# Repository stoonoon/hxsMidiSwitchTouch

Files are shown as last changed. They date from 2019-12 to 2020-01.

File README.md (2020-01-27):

# hxsMidiSwitchTouch
v2 of hxsMidiSwitcher - This time with touchscreen and expression pedal input

Still in the very early stages of how to go about this, so doubtless lots will change. That said, it's complete enough that my prototype unit is functional enough for me to use. Now I know I can make it work, I need to go back over it all and restructure the code so that it's less of a shambles.

At the moment the touchscreen is primarily to cycle between preset pages, but you can also tap the button labels to trigger a single press action.

The physical footswitches are working and sending midi messages over to the stomp. 
Expression pedal and toeswitch is working fairly well... I'm currently using a slightly modified crybaby wah with the circuit board removed, and a TRS jack connected to the potentiometer/toeswitch harness... Not ideal as it's a log pot rather than a linear one but with some software compensation it seems good enough for now.

# Combo press / long press actions
 - Switch layout:
[0 1 2 3]
[4 5 6 7]
- Combo press (all pages)
-- 0+4 - Preset Down
-- 3+7 - Preset Up
-- 6+7 - Tuner
-- 0+1 - switcher Page Down
-- 2+3 - switcher Page Up
- Long Press (all pages)
-- 3 - Tuner

## Working so far
- Touchscreen
-- << and >> buttons cycle between preset pages
-- Footswitch labels update as preset page changes
-- Touching the footswitch label triggers a FS short click action for that switch
- Midi
-- PC / CC messages
-- macro of several messages sent in a chain (needed for preset up/down functionality without relying on FS4/FS5 being dedicated to it in the Stomp global settings)
- Expression pedal
-- Converts resistance from 100kOhm log pot to MIDI byte
-- Sends to Stomp as either EXP1, EXP2 or both
-- Checks for changes in latching toeswitch & sends FS5 to Stomp
- switch preset page from footswitches
- toggle mode (FS function & label changes to next in list after press) - see looper Fwd/Rev and Full/Half speed for an example

## Still to do:
- Refactor the code so it plays nicely in VSCode - it doesn't seem to like multiple .ino files
- Move current_millis declaration from global to local in whichever functions need it. (exp_pedal.ino)
- Move other exp pedal variables to static within functions where possible
- Rename MidiMessage/MidiMessageToggler/MidiNullMessage to FootswitchAction*
- 
- Programming screen on nextion & associated code on arduino
- Ability to save/load custom programs to/from eeprom
- Document the calculations for the expression pedal log pot compensation
- Document the wiring adapter for the wah pedal to expression pedal conversion.
- configurable for log/lin EXP pedal pots
- configurable for TRS pedal pot type input or TS + voltage divider style
- configurable for latching/momentary toeswitch
- configurable for +5v toeswitch with external pulldown, or GND toeswitch with internal pullup
- All the other stuff I can't remember at the moment or haven't thought of yet

## Maybe considering, but probably not until v3
- power capacitor needed for nextion screen? seems OK without.. will see if it holds up
- activate long press/double FS actions from touchscreen 
- USB host midi capability - to be able to control Zoom B3/G3n/MS60B type pedals etc
- extra MIDI in/out ports
- bluetooth
- self-hovering

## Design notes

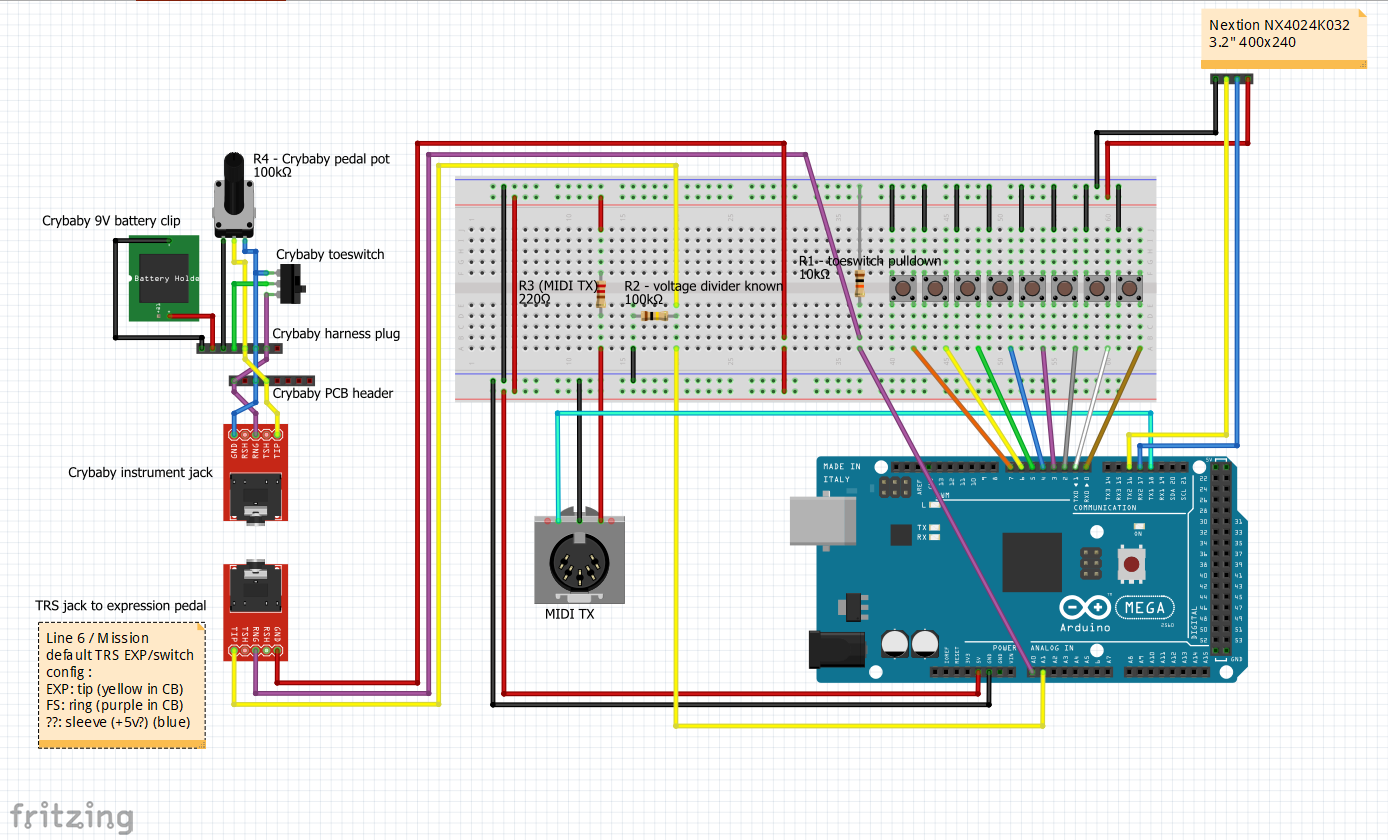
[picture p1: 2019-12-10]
hxsMidiSwitchTouch-breadboard.png

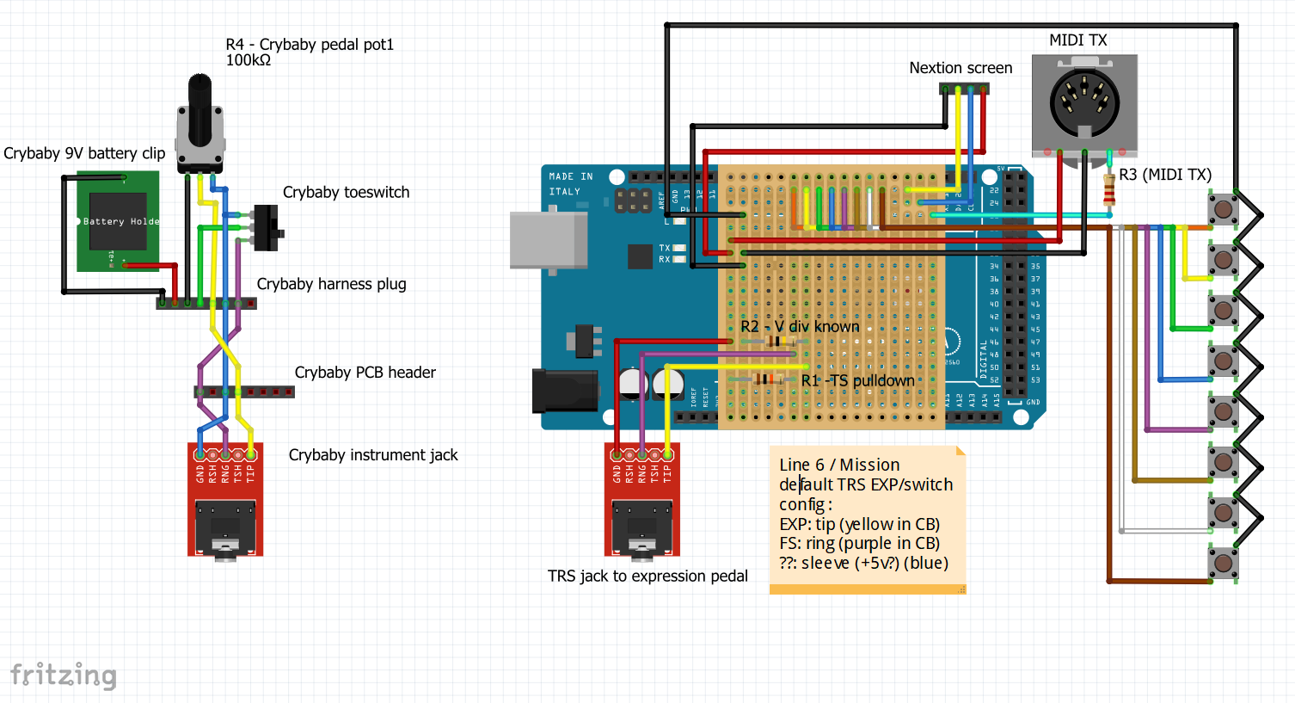
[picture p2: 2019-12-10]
hxsMidiSwitchTouch-shield.png

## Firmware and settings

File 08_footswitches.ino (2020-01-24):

//default config for footswitch single tap actions
MidiMessage *page0SingleActions[] = {&hxsSnap1, &hxsSnap2, &hxsSnap3, &hxsTuner, 
                            &hxsFS1, &hxsFS2, &hxsFS3, &hxsTapTempo};
MidiMessage *page1SingleActions[] = {&hxsSnap1, &hxsSnap2, &hxsSnap3, &hxsFS5, 
                        &hxsFS1, &hxsFS2, &hxsFS3, &hxsFS4};
MidiMessage *page2SingleActions[] = {&hxsSnap1, &hxsSnap2, &hxsSnap3, &hxsPresetUpMacro, 
                        &hxsFS1, &hxsFS2, &hxsFS3, &hxsPresetDownMacro};
MidiMessage *page3SingleActions[] = {&hxsFS4, &hxsFS5, &hxsPresetDownMacro, &hxsPresetUpMacro, 
                        &hxsFS1, &hxsFS2, &hxsFS3, &hxsTapTempo};
MidiMessage *page4SingleActions[] = {&hxsFS4, &hxsFS5, &hxsPresetDownMacro, &hxsPresetUpMacro,
                        &hxsSnap1, &hxsSnap2, &hxsSnap3, &hxsTapTempo};
MidiMessage *page5SingleActions[] = {&hxsPC01A, &hxsPC01B, &hxsPC01C, &hxsTuner,
                        &hxsPC02A, &hxsPC02B, &hxsPC02C, &hxsTapTempo};
MidiMessage *page6SingleActions[] = {&hxsLooperOverdub, &hxsLooperRec, &hxsLooperRevToggle, &hxsLooperSpeedToggle,
                        &hxsLooperStop, &hxsLooperPlay, &hxsLooperPlayOnce, &hxsLooperUndoRedo};
    


void setupFootSwitches() { //configure pins and attach debouncers
  for (int i=0; i<footSwitchCount; i++) {
    fsDebouncers[i] = Bounce();
    pinMode(footSwitchPin[i], INPUT_PULLUP);
    fsDebouncers[i].attach(footSwitchPin[i]);
    fsDebouncers[i].interval(5); //interval in ms
    footSwitchCurrentValue[i] = footSwitchUp;
  }//for loop
}//setupFootSwitches()

void setupFootSwitchActions() { //initialise individualSwitchAction array with preset config
    //start by initialising all action pointers to &blankMidiMsg
    for (int fsA=0; fsA<footSwitchCount; fsA++) { //iterate over all footswitches
        for (int pg=0; pg<totalPresetPages; pg++) { //iterate over all preset pages
            for (int act=0; act<individualActionTypeCount; act++) { //iterate over all switch action types
                individualSwitchAction[fsA][pg][act]=&blankMidiMsg;
            }//for(act)
        }//for (pg)
        for (int fsB =0; fsB<footSwitchCount; fsB++) { //iterate over all switches again so all combinations are covered
            setComboAction(-1,fsA,fsB,&blankMidiMsg); //set blank action on all pages
        }//for(fsB)
    }//for (fsA)
    
    //set predefined actions
    setWholePageActions(0,SINGLE,page0SingleActions);
    setWholePageActions(1,SINGLE,page1SingleActions);
    setWholePageActions(2,SINGLE,page2SingleActions);
    setWholePageActions(3,SINGLE,page3SingleActions);
    setWholePageActions(4,SINGLE,page4SingleActions);
    setWholePageActions(5,SINGLE,page5SingleActions);
    setWholePageActions(6,SINGLE,page6SingleActions);
    
    //set predefined long press actions
    
    //individualSwitchAction[0][0][LONG]=&hxsTuner;
    setAllPagesAction(3, LONG, &hxsTuner);
    
    //set predefined combination actions
    setComboAction(-1, 0, 4, &hxsPresetDownMacro);
    setComboAction(-1, 3, 7, &hxsPresetUpMacro);
    setComboAction(-1, 6, 7, &hxsTuner);
    setComboAction(-1, 0, 1, &switcherPageDown);
    setComboAction(-1, 2, 3, &switcherPageUp);
        
}//setupFootSwitchActions()

void setAllPagesAction(int fs, individualActionType action, MidiMessage *msg) { // set an action which applies to all pages
  for (int p=0; p<totalPresetPages; p++) {
    individualSwitchAction[fs][p][action]=msg;
  }//for loop
} //setAllPagesAction

void setWholePageActions(int page, individualActionType action, MidiMessage *msg[footSwitchCount]) { //set all FS actions for a single page and action type
    for (int fs=0; fs<footSwitchCount; fs++) {
        individualSwitchAction[fs][page][action]=msg[fs];
    }
}//setWholePageActions

void setComboAction(int page, int fsA, int fsB, MidiMessage *msg) { //set an action for a 2x switch combination press
    //we need to sort the switches by index so we never have conficting settings with switch indexes swapped
    int lowestSwitchIndex; 
    int highestSwitchIndex;
    if (fsA<fsB) {
        lowestSwitchIndex=fsA;
        highestSwitchIndex=fsB;
        }
    else {
        lowestSwitchIndex=fsB;
        highestSwitchIndex=fsA;
        }
    if (page==-1) {//then apply this combo to all pages
        for (int p=0; p<totalPresetPages; p++) {
            comboSwitchAction[lowestSwitchIndex][highestSwitchIndex][p]=msg;
        }//for loop
    }//if (page==-1)
    else {//then only apply it to a single page
        comboSwitchAction[lowestSwitchIndex][highestSwitchIndex][page]=msg;
    }//else
}//setComboAction

void updateScreenLabels() { //update Nextion screen with text labels from current page single click action MidiMessages
    for (int sw =0; sw<footSwitchCount;sw++) {
        for (int line=0; line<labelLinesPerSwitch;line++) {
            footSwitchScreenLabels[sw][line]->setText( individualSwitchAction[sw][currentPage][SINGLE]->label[line] );
        }//for(line)
    } //for (sw)
}//updateScreenLabels()

bool fsIndexIsValid (int fsIndex){ //function to check if a given int is a valid footswitch index
        if ((fsIndex >= 0) && (fsIndex < footSwitchCount) ) { //then switchIndex is valid
            return true;
            }
        else {
            return false;
            }   
}// fsIndexIsValid
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

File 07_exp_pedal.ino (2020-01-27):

// #define PEDAL_DEBUG

// pretty sure these next 3 can be made static variables within readExpPedalCC()
byte lastExpPedalCCsent = 0; // the last CC value we sent. (No point in sending more if the pedal hasn't moved!)
unsigned long lastExpPedalCCsentMillis = millis(); // the time we last sent a message. 
const unsigned int minExpPedalUpdateDelay = 4; // how many milliseconds we wait before sending another pedal position message


unsigned long currentMillis; // pretty sure this doesn't need to be a global as it should always be updated with millis() whenever we use it. Will change this next time I'm compiling & testing, but I'm just adding comments away from the IDE at the moment.

const int toeSwitchUpdateDebounceTime = 50; // minimum elapsed time in ms since last toeSwitch press before we consider acting on another one

const int maxR2 = 100000; // R2 value above which we consider pedal to be fully toe down. Reduce this to increase toedown deadzone (my max measured value was about 103000)
const int minR2 = 5000; // R2 value below which we consider pedal to be fully heel down. Reduce this to increase heeldown deadzone (my min measured value was about 100)


byte readPedalPos() { // should probably be renamed getCurrentPedalPosition()
/*
 *  Read value from expression pedal input pin, and return a 0-127 value for use as a MIDI CC
 *  
 *  This is a specific implementation based on my hardware, and may need to be changed substantially
 *  based on what expression pedal setup you use.
 *
 *  I have a pedal with a 100k ohm log pot and toeswitch connected to my controller via a single TRS cable
 *  so I have +5V going to one of the fixed ends of the track, and the wiper is connected to the input pin
 *  on the Arduino via a voltage divider circuit on my arduino shield.
 *
 *  If you are not planning on using a toeswitch, or plan to run a separate cable to your toeswitch, 
 *  then you could run +5V and GND to either end of the track and connect the wiper to the Arduino input
 *  pin without requiring the voltage divider circuit. 
 *
 *  If you are using a linear pot in your expression pedal (most will be, unless you're using a half-
 *  converted wah pedal like me) then you should be able to simplify the mapping from R2 to pdl
 *  as they should rise proportionally to each other through the full extent of any travel (give or
 *  take any exceptions for deadzones at end of travel)
*/
    float Vout= 0; // voltage divider output, as measured at analog input pin
    float R2= 0; // calculated resistance of variable pot in expression pedal
    float buffer= 0;
    int raw = analogRead(analogExpressionPedalPin);
    if(raw) {
        buffer = raw * Vin;
        Vout = buffer / 1024.0;
        buffer = (Vin/Vout) -1;
        R2 = R1 * buffer;
        float pdl;
        if (R2 > maxR2) { // then fully toe down (or within deadzone)
        pdl= 127;
    }
    else if (R2 < minR2) { //then fully heel down (or within deadzone)
        pdl= 0;
    }
    else if (R2 > 84000) { // then on toe down end of track
        pdl = mapf(R2, 88000, 100000, 66.6, 127);
    }
    else { // on heel down end of track
        pdl = mapf(R2, 97.75, 81000, 0, 54);
    }
    #ifdef PEDAL_DEBUG
    debugPedalInfo(R2, byte(pdl));
    #endif
    return byte(pdl);
    } //if(raw)
    else return 0;
}// byte readPedalPos()


void readExpPedalCC() { // should probably be renamed updateExpPedalPositionCC()
  byte currentExpPedalCC = readPedalPos();
  if (currentExpPedalCC != lastExpPedalCCsent) { // then pedal has moved
    currentMillis = millis();
    if ( currentMillis > (lastExpPedalCCsentMillis + minExpPedalUpdateDelay) ) { //then enough time has elapsed since last CC sent
        if (currentEXPpedal == BOTH | EXP1) {
            MIDI.sendControlChange(1,currentExpPedalCC,1);
        }
        if (currentEXPpedal == BOTH | EXP2) {
            MIDI.sendControlChange(2,currentExpPedalCC,1);
        }
      lastExpPedalCCsent = currentExpPedalCC;
      lastExpPedalCCsentMillis = currentMillis;
    }
  } 
} //readExpPedalCC()


void readExpToeswitch() {
/*
 *
 *  This code is based on my hardware setup which uses a latching footswitch, and shares a TRS connection
 *  with the expression pedal pot... Hence no spare wire for a GNS connection, so I used the +5V on the 
 *  other pole of the switch, and a pulldown resistor on my arduino shield. 
 *
 *  If you have the toeswitch connected to GND instead of +5V, you can omit the external pulldown, and 
 *  connect the switch direct to the arduino input pin - but remember to set the internal pullup
 *
 *  If you are using a momentary switch then don't use this code - just use a "Bounce" debouncer as
 *  used for the rest of the footswitches
 *
 */
 
 
  static int lastToeSwitchState = digitalRead(expToeswitchPin);
  static unsigned long lastToeSwitchUpdateSentMillis = millis();
  int currentToeSwitchState = digitalRead(expToeswitchPin);
  if (lastToeSwitchState != currentToeSwitchState) { // switch has been pressed since last update sent
    currentMillis = millis();
    if ( currentMillis > (lastToeSwitchUpdateSentMillis + toeSwitchUpdateDebounceTime)) {
      MIDI.sendControlChange(53,0,1);//FS5
      lastToeSwitchState = currentToeSwitchState;
      lastToeSwitchUpdateSentMillis = currentMillis;
    }
  }
}

float mapf(float x, float in_min, float in_max, float out_min, float out_max)
// maps value x from range (in_min to in_max) to range (out_min to out_max)
{
    return (x - in_min) * (out_max - out_min) / (in_max - in_min) + out_min;
}



#ifdef PEDAL_DEBUG
void debugPedalInfo(float R, byte p) {// debug tester to report measured values of R2 to aid in pedal calibration}
    const int updatePeriod = 1000; // delay time between reports
    unsigned long currentMillis = millis();
    static unsigned long lastResistanceDisplay = currentMillis;
    if ((currentMillis-lastResistanceDisplay) > updatePeriod) {
        Serial.print("EXP pedal measured resistance = ");
        Serial.print(R);
        Serial.print(", calculated MIDI value: ");
        Serial.println(p);
        lastResistanceDisplay=millis();
        }
}//printR2
#endif

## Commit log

2019-11-25 added 1st draft of breadboard layout
    [hxsMidiSwitchTouch-breadboard.fzz]
2019-11-27 Changed data structure for MidiMessage class to avoid code repetition and needless MidiMacro wrappers.
    [02_globals.ino, 03_prototypes.ino, 07_footswitches.ino]
2019-11-29 added EXP pedal calibration debug code and fixed error in R to pos mapping
2019-11-30 added short press action to footswitch hotspots on touchscreen
    [02_globals.ino, 05_nextion.ino, 06_midi.ino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]
2019-11-30 moved pedal config to globals and type fix
    [02_globals.ino, 07_exp_pedal.ino]
2019-12-10 added provisional arduino shield schematic and switched TRS wiring to match Line6/Mission pedal pinout
    [hxsMidiSwitchTouch-breadboard.fzz, hxsMidiSwitchTouch-shield.fzz]
2020-01-22 update to match the one I built
    [hxsMidiSwitchTouch-shield.fzz]
